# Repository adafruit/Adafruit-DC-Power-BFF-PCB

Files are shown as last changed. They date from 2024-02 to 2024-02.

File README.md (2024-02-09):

## Adafruit DC Power BFF Add-On for QT Py PCB

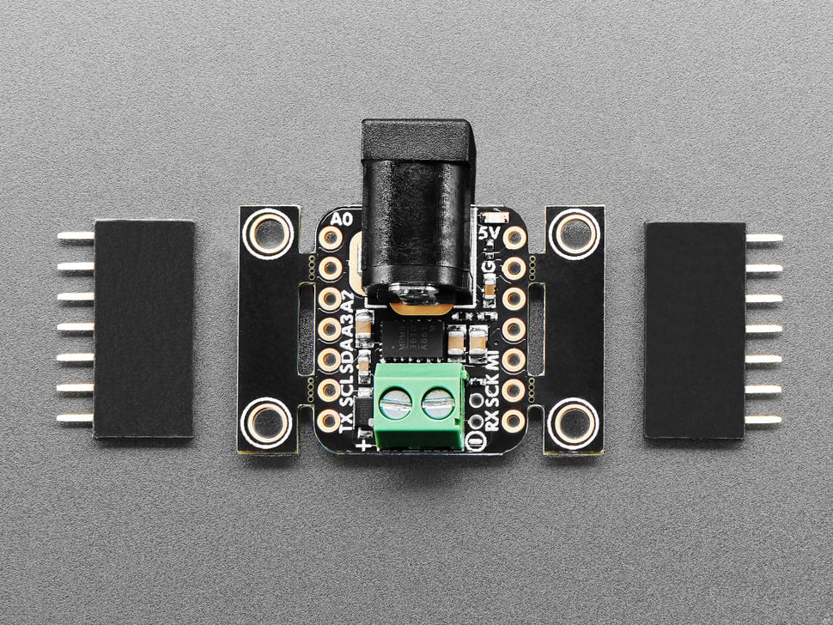
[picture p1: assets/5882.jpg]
<a href="http://www.adafruit.com/products/5882"><br/>
Click here to purchase one from the Adafruit shop</a>

PCB files for the Adafruit DC Power BFF Add-On for QT Py. 

Format is EagleCAD schematic and board layout
* https://www.adafruit.com/product/5882

### Description

We were recently working on a project where we really wanted to power a QT Py ESP32 from 12V - but the only power input on the board is basically USB 5V max. Never one to give up, we designed an add-on that will allow anyone to use a QT Py or Xiao dev board with up to 20V DC power!

In the center is an MPM3610 integrated buck converter, which will generate 5V from up to 20V input, with cool DC/DC technology so there's no heat-sink needed. The MPM3610 can give about 1 Amp output, which should be plenty even if you have LEDs, WiFi connectivity, displays or even a small motor or servo.

The board features both 3.5mm terminal block and 2.1mm DC jack inputs, protected with a Schottky diode. You can use either to power the board, but don't plug in different power inputs to both - they're wired directly together on the BFF. If you're using the DC jack to power, you can use the terminal block as an 'pass through output' to connect other high-voltage devices.

There's two small enable and an ground solderable pads next to the terminal block so you can use an external switch to disable the converter. 

Since its a bulky add-on with through hole components, compared to most of our other BFF boards, we think it's best to use socket header to plug a QT Py on top, rather than trying to have it solder back-to-back. For that reason we include two 7-pin socket headers. Solder them so that the QT Py sits on the top, there's two break-apart railings that can be used to bolt the board since plugging in a jack requires  mechanical stabilization.

### License

Adafruit invests time and resources providing this open source design, please support Adafruit and open-source hardware by purchasing products from [Adafruit](https://www.adafruit.com)!

Designed by Limor Fried/Ladyada for Adafruit Industries.

Creative Commons Attribution/Share-Alike, all text above must be included in any redistribution. 
See license.txt for additional details.

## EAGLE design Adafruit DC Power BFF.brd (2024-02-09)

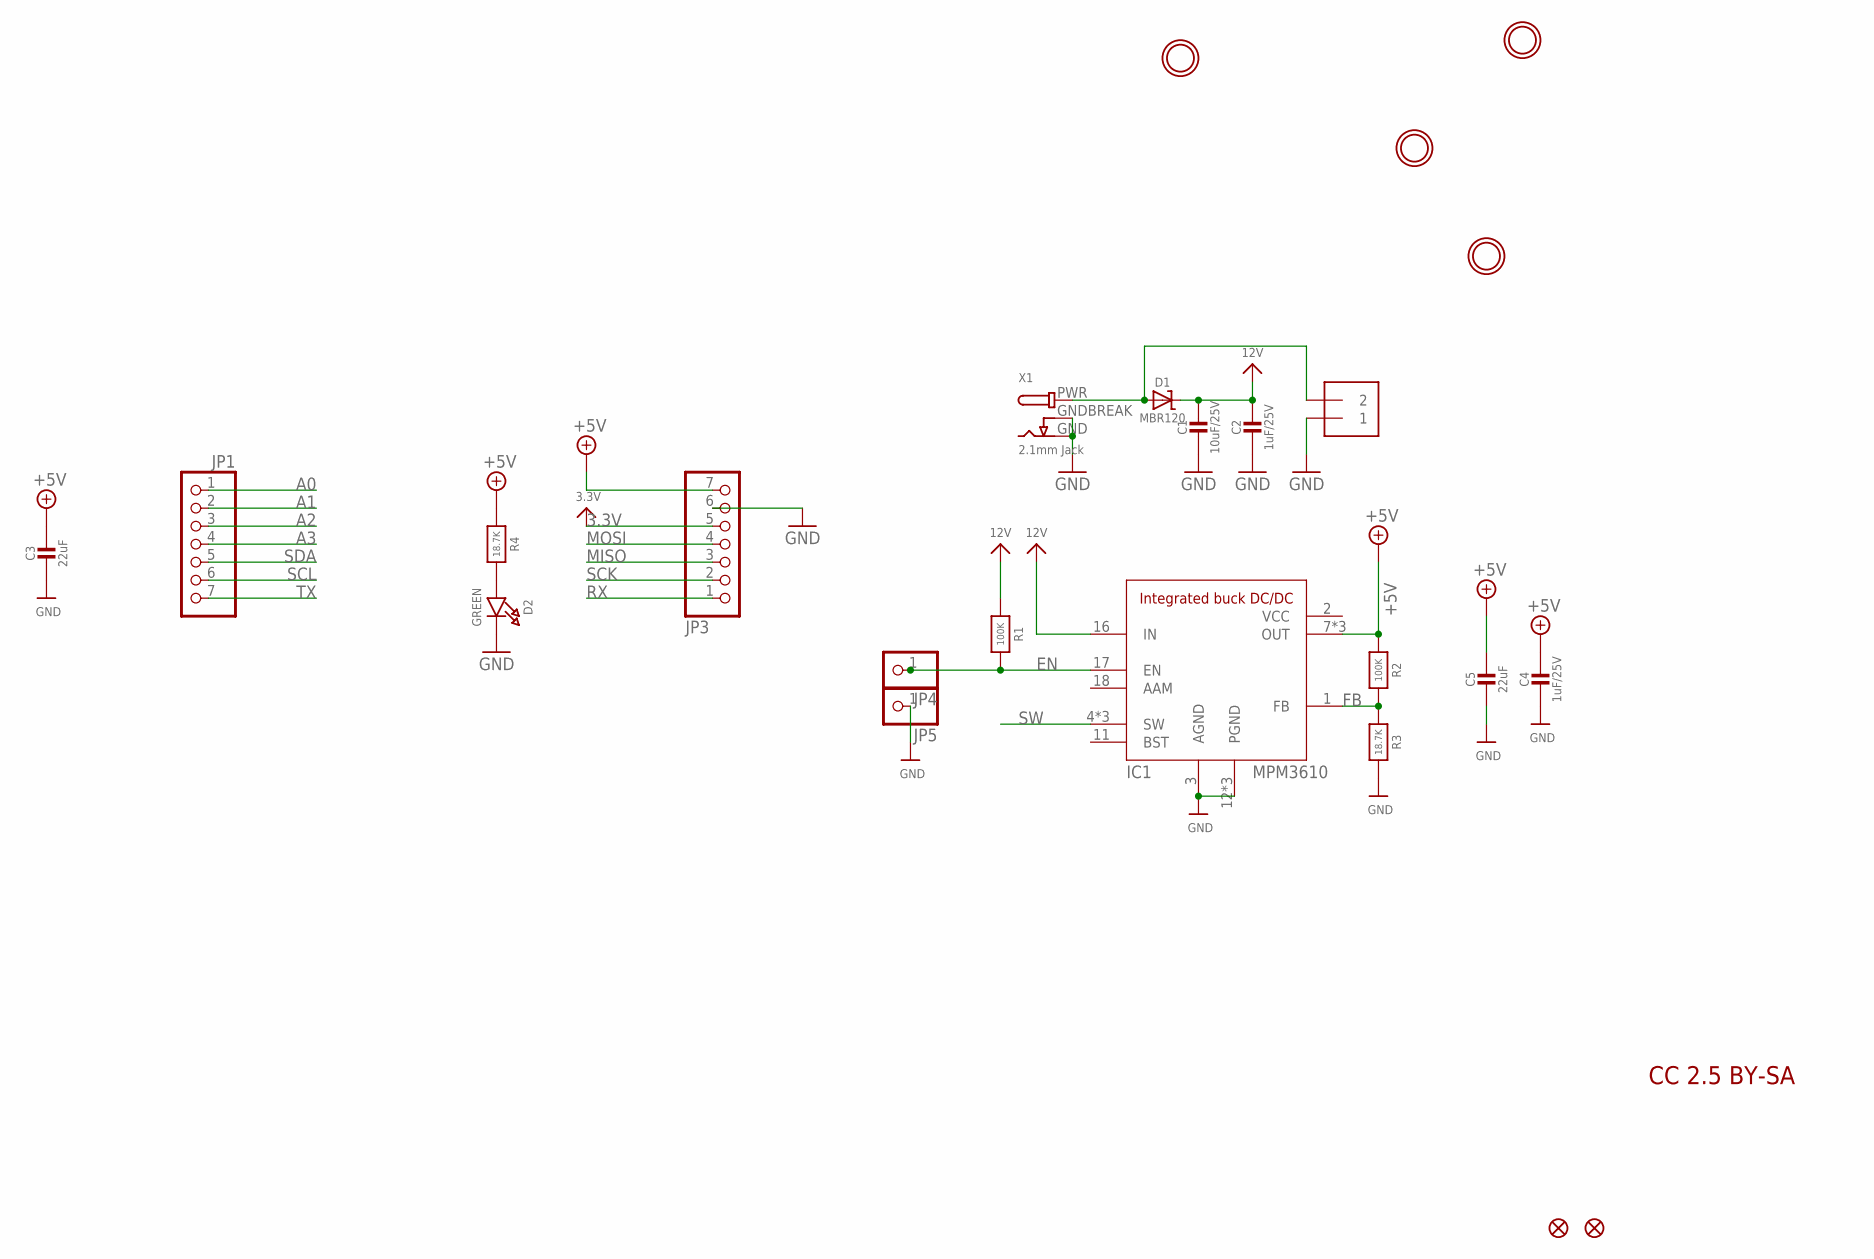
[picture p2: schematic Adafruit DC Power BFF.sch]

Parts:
C1: 10uF/25V; 0805-NO
C2, C4: 1uF/25V; 0603-NO
C3, C5: 22uF; 0805-NO
D1: MBR120; SOD-123FL
D2: GREEN; CHIPLED_0603_NOOUTLINE
IC1: MPM3610
J1: 1X2-3.5MM
JP1, JP3: HEADER-1X7THICKER; 1X07_ROUND_76
JP4, JP5: HEADER-1X12MM; 1X01_2MM
R1, R2: 100K; _0402NO
R3, R4: 18.7K; _0402NO
U$6, U$8: FIDUCIAL_1MM
U$14, U$15, U$17, U$18: MOUNTINGHOLE2.5; MOUNTINGHOLE_2.5_PLATED
X1: 2.1mm Jack; DCJACK_2MM_PTH

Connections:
3.3V: JP3.5
12V: C1.1, C2.1, D1.C, IC1.16 (IN), R1.1
+5V: C3.1, C4.1, C5.1, IC1.7 (OUT), IC1.8 (OUT), IC1.9 (OUT), JP3.7, R2.1, R4.1
A0: JP1.1
A1: JP1.2
A2: JP1.3
A3: JP1.4
EN: IC1.17 (EN), JP4.1, R1.2
FB: IC1.1 (FB), R2.2, R3.1
GND: C1.2, C2.2, C3.2, C4.2, C5.2, D2.C, IC1.3 (AGND), IC1.12 (PGND), IC1.13 (PGND), IC1.14 (PGND), J1.1, JP3.6, JP5.1, R3.2, X1.GND, X1.GNDBREAK
MISO: JP3.3
MOSI: JP3.4
unnamed: D2.A, R4.2
unnamed: D1.A, J1.2, X1.PWR
RX: JP3.1
SCK: JP3.2
SCL: JP1.6
SDA: JP1.5
SW: IC1.4 (SW), IC1.5 (SW), IC1.6 (SW)
TX: JP1.7
VCC: IC1.2 (VCC)

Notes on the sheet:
CC 2.5 BY-SA

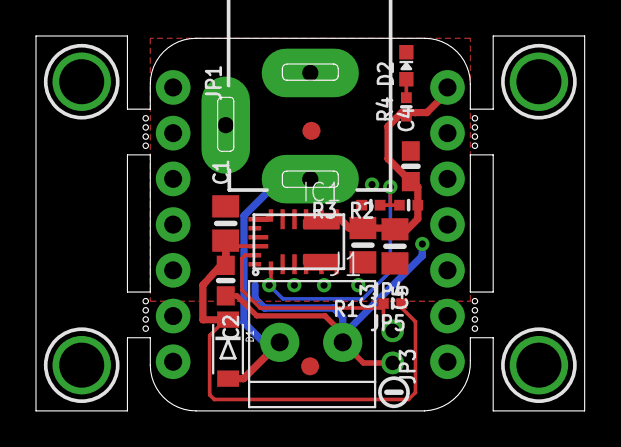
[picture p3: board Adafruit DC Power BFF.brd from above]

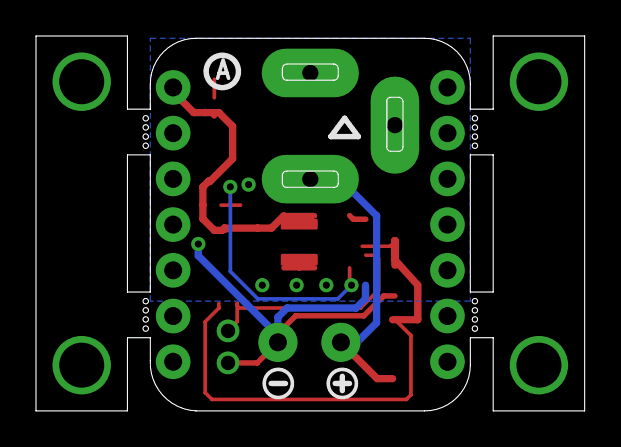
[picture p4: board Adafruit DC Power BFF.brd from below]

Board: 2 copper layers, 30.5 x 20.8 mm, 42 parts (5 on the bottom side), 8 nets.

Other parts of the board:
PLABEL1: PLABEL1
PLABEL2: PLABEL2
PLABEL3: PLABEL3
PLABEL5: PLABEL5
PLABEL6: PLABEL6
PLABEL7: PLABEL7
PLABEL8: PLABEL8
PLABEL11: PLABEL11
PLABEL12: PLABEL12
PLABEL13: PLABEL13
PLABEL14: PLABEL14
PLABEL19: PLABEL19
PLABEL20: PLABEL20
PLABEL21: PLABEL21
U$3: PCBFEAT-REV-040
U$12, U$20: SYMBOL_MINUS
U$19: SYMBOL_PLUS

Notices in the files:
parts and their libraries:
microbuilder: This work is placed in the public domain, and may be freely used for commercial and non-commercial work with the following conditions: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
